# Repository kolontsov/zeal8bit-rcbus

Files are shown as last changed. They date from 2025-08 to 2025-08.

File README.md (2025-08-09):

## Zeal 8-bit to RCBus adapter

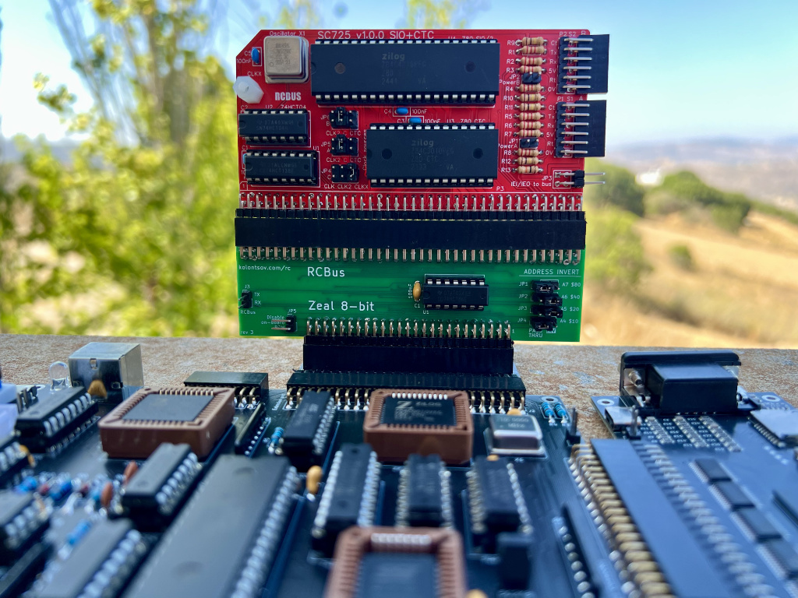
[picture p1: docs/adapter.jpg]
PCB


This is a simple adapter enabling the use of RC2014 and [RCBus](https://smallcomputercentral.com/rcbus/) boards with the [Zeal 8-bit computer](https://zeal8bit.com/) [external port](https://zeal8bit.com/docs/ext_port/) or [backplane](https://www.tindie.com/products/zeal8bit/backplane-pcb-for-zeal-8-bit-computer-4-slots/), with optional port mapping.

Port mapping is important because many RCBus boards use ports larger than 0x80, which is [reserved I/O space](https://zeal8bit.com/docs/memorymap/#io-mapping) on the Zeal 8-bit computer.

To make the board compatible with Zeal 8-bit, any of the A7-A4 address lines can be **inverted** -- see [online configuration tool](https://kolontsov.github.io/zeal8bit-rcbus/).

Tested with:
- [SC729 – RCBus Compact Flash Module](https://smallcomputercentral.com/rcbus/sc700-series/sc729-rcbus-compact-flash-module/) (with [Zeal 8-bit OS](https://github.com/Zeal8bit/Zeal-8-bit-OS))
- [SC725 – RCBus Serial and Timer Module](https://smallcomputercentral.com/rcbus/sc700-series/sc725-rcbus-serial-and-timer-module/) (with RomWBW)
- [16C2552 dual UART for RC2014](https://hackaday.io/project/170819-16c2552-dual-uart-for-rc2014) (with RomWBW)
- (to be added)

No guarantee that it will work with other RCBus boards, but it should be compatible with most of them.

### Bill of Materials

Reference | Description                                    | Comment
--------- | ---------------------------------------------- | --------------------------------------
J1        | 2x25 pin header, 2.54 mm, right angle          | Plugs into Zeal 8-bit backplane
J2        | 2x40 *or* 1x40 pin socket, 2.54mm, right angle | Socket for RCBus board to plug into
JP1, JP2, JP3, JP4 | 2-pin header                          | A7-A4 invert jumpers
U1        | 74HCT86 (DIP-14), with optional socket         | Quad 2-input XOR gate
C1        | 0.1µF ceramic capacitor                        |
JP5       | 2-pin header, 2.54mm                           | (optional) Disable Zeal 8-bit on-board ROM
J3        | 2-pin header, 2.54mm                           | (optional) RX/TX pins of RCBus

### PCB

- Gerber files are in [production](production/) directory (JLCPCB, PCBWay, etc.)
- Read-to-order PCB at [PCBWay](https://www.pcbway.com/project/shareproject/Zeal_8_bit_to_RCBus_adapter_069f3f1e.html)
- Schematics in PDF format: [zeal8bit-rcbus.pdf](docs/zeal8bit-rcbus.pdf)
- KiCad 9.0 project in this directory

### Assembly

In most cases, using a 40-pin socket for connecting RCBus boards is sufficient and easier to use than an 80-pin socket, especially if you need to connect and disconnect frequently.

An 80-pin socket is only required if your RCBus board actually uses the NMI, WAIT, BUSRQ, BUSACK, HALT or A16..A21 lines.

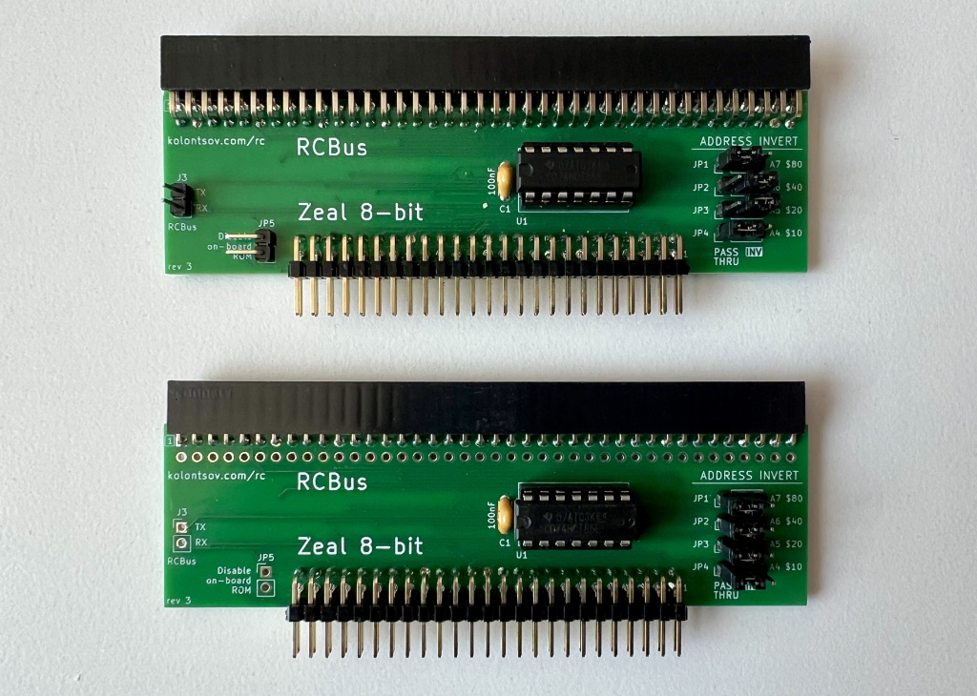
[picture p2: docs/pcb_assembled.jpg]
PCB with components


### Configuration

Use the [online configuration tool](https://kolontsov.github.io/zeal8bit-rcbus/) to determine which address lines (A7-A4) need inversion for your specific RCBus board. Set jumpers JP1-JP4 accordingly.

### License

Licensed under [CERN-OHL-P v2](LICENSE).

All trademarks are the property of their respective owners, use of these names does not imply endorsement.

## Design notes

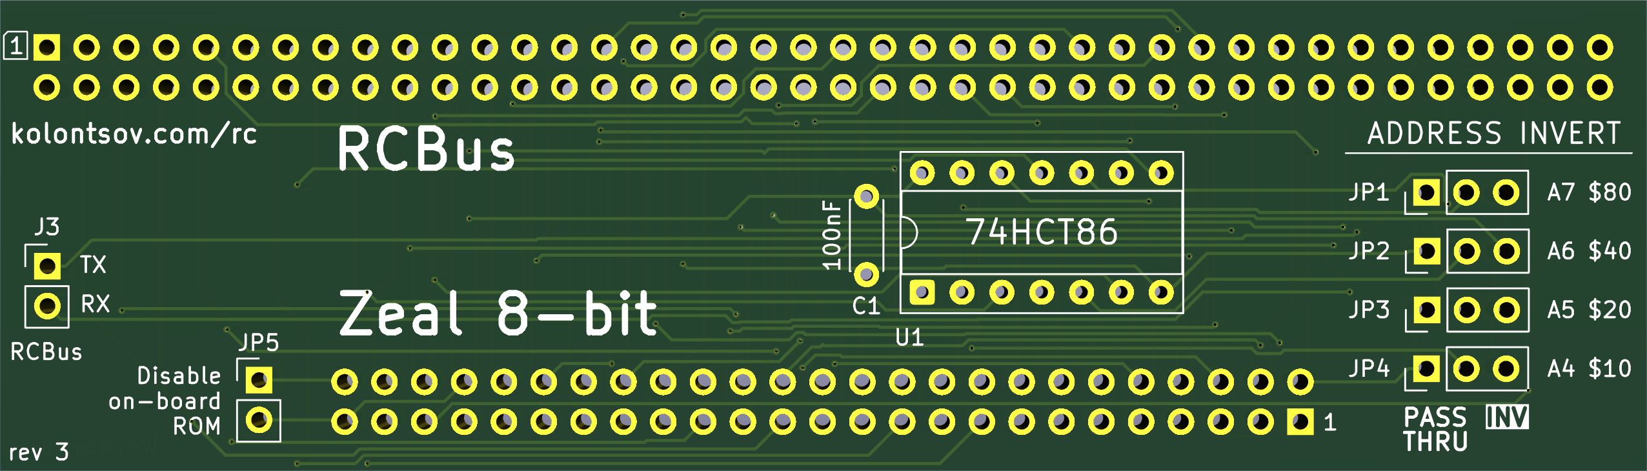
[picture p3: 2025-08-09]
docs/pcb.png

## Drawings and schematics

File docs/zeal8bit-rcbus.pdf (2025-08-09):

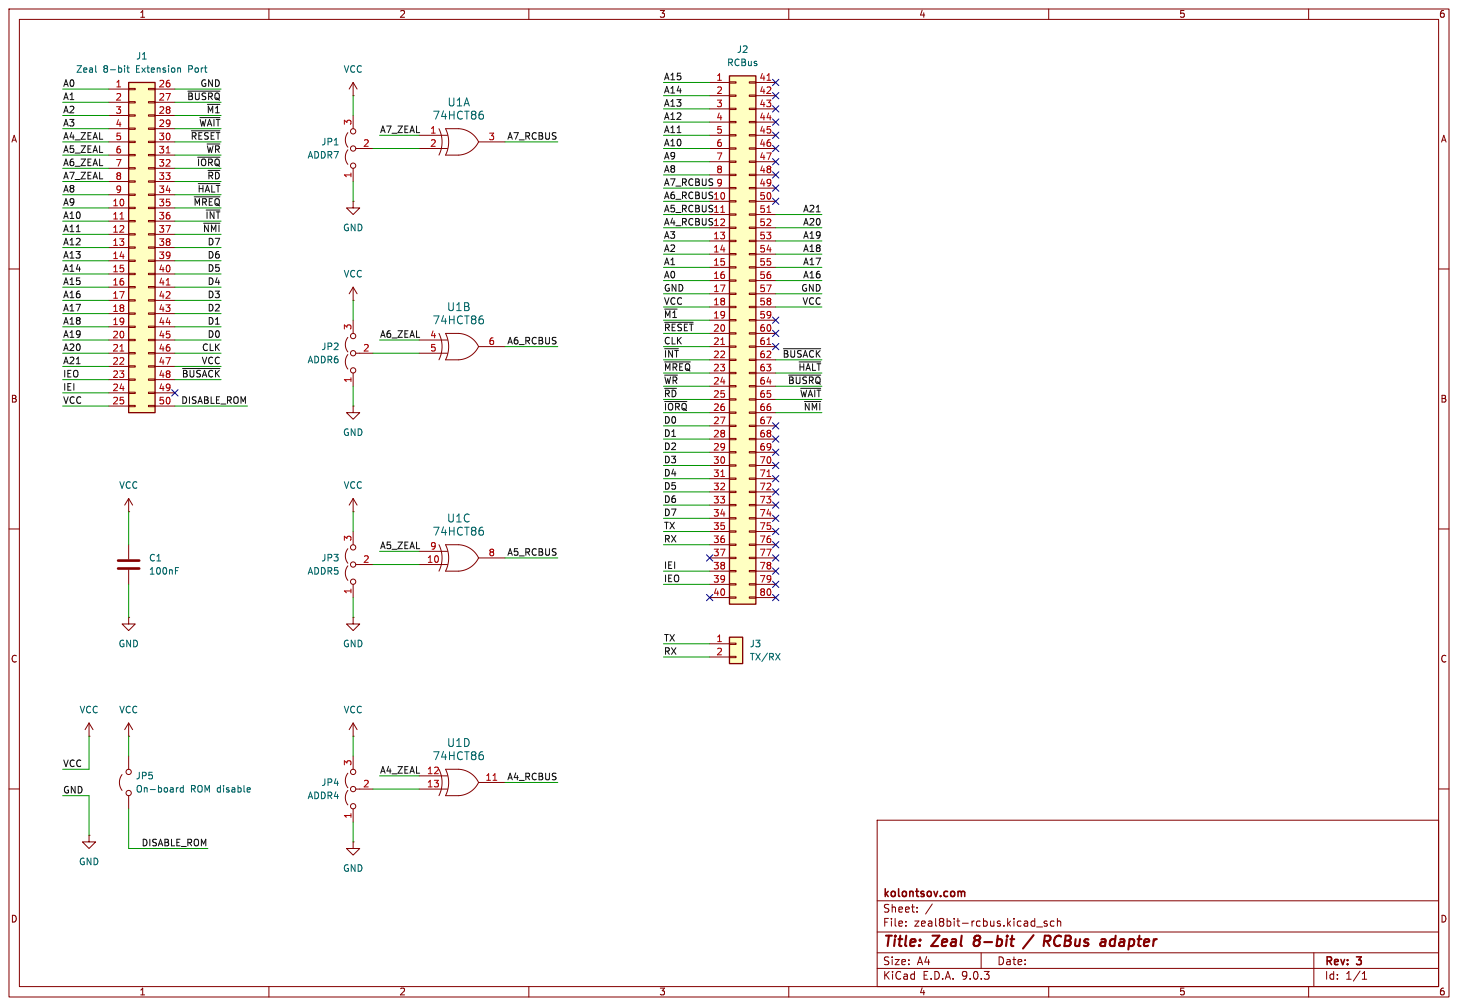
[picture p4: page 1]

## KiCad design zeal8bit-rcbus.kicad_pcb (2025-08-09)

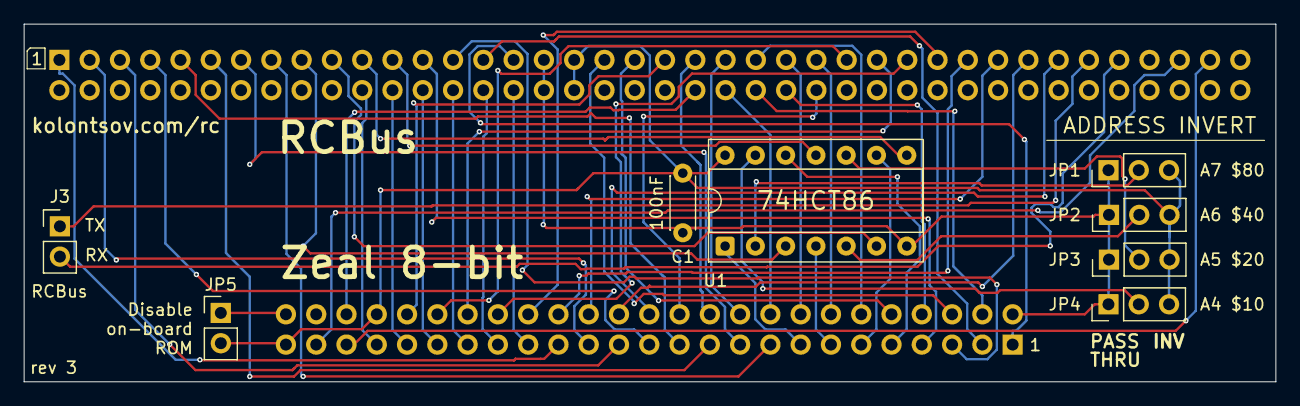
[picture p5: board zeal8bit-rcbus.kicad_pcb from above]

Board: 2 copper layers, 105.0 x 30.0 mm, 10 parts (0 on the bottom side), 58 nets.

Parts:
C1: 100nF; C_Disc_D4.3mm_W1.9mm_P5.00mm
J1: Zeal 8-bit Extension Port; PinHeader_2x25_P2.54mm_Horizontal
J2: RCBus; PinSocket_2x40_P2.54mm_Horizontal
J3: TX/RX; PinHeader_1x02_P2.54mm_Vertical
JP1: A7 $80; PinHeader_1x03_P2.54mm_Vertical
JP2: A6 $40; PinHeader_1x03_P2.54mm_Vertical
JP3: A5 $20; PinHeader_1x03_P2.54mm_Vertical
JP4: A4 $10; PinHeader_1x03_P2.54mm_Vertical
JP5: ROM; PinHeader_1x02_P2.54mm_Vertical
U1: 74HCT86; DIP-14_W7.62mm_Socket

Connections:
/A0: J1.1, J2.16
/A1: J1.2, J2.15
/A2: J1.3, J2.14
/A3: J1.4, J2.13
/A4_RCBUS: J2.12, U1.11
/A4_ZEAL: J1.5, U1.12
/A5_RCBUS: J2.11, U1.8
/A5_ZEAL: J1.6, U1.9
/A6_RCBUS: J2.10, U1.6
/A6_ZEAL: J1.7, U1.4
/A7_RCBUS: J2.9, U1.3
/A7_ZEAL: J1.8, U1.1
/A8: J1.9, J2.8
/A9: J1.10, J2.7
/A10: J1.11, J2.6
/A11: J1.12, J2.5
/A12: J1.13, J2.4
/A13: J1.14, J2.3
/A14: J1.15, J2.2
/A15: J1.16, J2.1
/A16: J1.17, J2.56
/A17: J1.18, J2.55
/A18: J1.19, J2.54
/A19: J1.20, J2.53
/A20: J1.21, J2.52
/A21: J1.22, J2.51
/CLK: J1.46, J2.21
/D0: J1.45, J2.27
/D1: J1.44, J2.28
/D2: J1.43, J2.29
/D3: J1.42, J2.30
/D4: J1.41, J2.31
/D5: J1.40, J2.32
/D6: J1.39, J2.33
/D7: J1.38, J2.34
/DISABLE_ROM: J1.50, JP5.1 (A)
/IEI: J1.24, J2.38
/IEO: J1.23, J2.39
/RX: J2.36, J3.2
/TX: J2.35, J3.1
/~BUSACK: J1.48, J2.62
/~BUSRQ: J1.27, J2.64
/~HALT: J1.34, J2.63
/~INT: J1.36, J2.22
/~IORQ: J1.32, J2.26
/~M1: J1.28, J2.19
/~MREQ: J1.35, J2.23
/~NMI: J1.37, J2.66
/~RD: J1.33, J2.25
/~RESET: J1.30, J2.20
/~WAIT: J1.29, J2.65
/~WR: J1.31, J2.24
GND: C1.2, J1.26, J2.17, J2.57, JP1.1 (A), JP2.1 (A), JP3.1 (A), JP4.1 (A), U1.7 (GND)
unnamed: JP1.2 (C), U1.2
unnamed: JP2.2 (C), U1.5
unnamed: JP3.2 (C), U1.10
unnamed: JP4.2 (C), U1.13
VCC: C1.1, J1.25, J1.47, J2.18, J2.58, JP1.3 (B), JP2.3 (B), JP3.3 (B), JP4.3 (B), JP5.2 (B), U1.14 (VCC)

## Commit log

2025-08-09 initial revision
    [zeal8bit-rcbus.kicad_pcb, zeal8bit-rcbus.kicad_sch]
2025-08-09 add link to PCBWay project
